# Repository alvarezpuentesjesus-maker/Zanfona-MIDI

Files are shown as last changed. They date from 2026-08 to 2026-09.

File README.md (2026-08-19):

# Zanfona-MIDI

En este repositorio se recogen tanto los archivos de fabricación mecánica como el software y los esquemas electrónicos para la fabricación de un prototipo funcional de una zanfona MIDI. Este proyecto ha sido desarrollado como TFG para el grado en Robótica en la Universidad de Santiago de Compostela.

<p align="center">
  <a href="#">
    Terminada_Trasera
  </a>
</p>

## [Archivos_MIDI](Archivos_MIDI)

Para que el instrumento produzca sonido, es necesario conectarlo a un software de producción musical. En este caso se ha escogido [LMMS Studio](https://lmms.io/). 

Se han preparado archivos diferentes en esta carpeta, para interpretar varios instrumentos, gracias a la web de [Musical Artifacts](https://musical-artifacts.com/), que proporciona samples gratuitos.

## [Electrónica](Electronica) 

En esta carpeta están contenidos los diferentes esquemáticos utilizados en este proyecto. Además, se ha añadido el archivo de simulación empleado para la placa Resitor_Ladder, llamdo Simulación_Resistor_Ladder.txt.
Para emplear este archivo correctamente es necesario cargarlo en el simulador de circuitos de [MasterPLC](https://masterplc.com/simulador/).

Se adjunta aquí mismo una tabla con las conexiones de la placa principal para mayor facilidad de lectura:

<div align="center">

| Pin | Nombre | Conexión |
| :---: | :---: | :---: |
| 1 | GP0 | Manivela SDA |
| 2 | GP1 | Manivela SCL |
| 3 | GND | |
| 4 | GP2 | Display cuerdas 1 |
| 5 | GP3 | Display cuerdas 2 |
| 6 | GP4 | Display cuerdas 3 |
| 7 | GP5 | Display cuerdas 4 |
| 8 | GND | |
| 9 | GP6 | Display cuerdas 5 |
| 10 | GP7 | Display cuerdas 6 |
| 11 | GP8 | Display cuerdas 7 |
| 12 | GP9 | Display cuerdas 8 |
| 13 | GND | |
| 14 | GP10 | Display cuerdas 9 |
| 15 | GP11 | Display cuerdas Estado |
| 16 | GP12 | CLK Encoder Cuerdas |
| 17 | GP13 | DT Encoder Cuerdas |
| 18 | GND | |
| 19 | GP14 | SW Encoder Cuerdas |
| 20 | GP15 | CLK Encoder Perro |
| 21 | GP16 | DT Encoder Perro |
| 22 | GP17 | SW Encoder Perro |
| 23 | GND | |
| 24 | GP18 | CLK Encoder Bending |
| 25 | GP19 | DT Encoder Bending |
| 26 | GP20 | SW Encoder Bending |
| 27 | GP21 | NC |
| 28 | GND | |
| 29 | GP22 | NC |
| 30 | RUN | NC |
| 31 | GP26 A0 | Teclado Resistencias |
| 32 | GP27 A1 | NC |
| 33 | ADC GND | |
| 34 | GP28 A2 | Bending |
| 35 | ADV Vref | NC |
| 36 | 3v3 Vout | |
| 37 | 3v3 En | NC |
| 38 | GND | |
| 39 | VSYS 5V* | NC |
| 40 | VBUS 5V | |

</div>

## [Hardware](Hardware)

Aquí se ven contenidos los archivos de fabricación mecánica. Como archivo principal Archivo_Corte.CDR, permite el uso de una cortadora láser para fabricar todas las piezas necesarias en MDF de 3mm. Se facilitan también los archivos individuales de cada pieza en formato DXF en la carpeta [Piezas_individuales](Hardware/Piezas_individuales).

## [Software](Software)

Este proyecto se ha desarrollado utilizando una Raspberry Pi Pico como microcontrolador principal. A su vez, se ha necesitado el firmware de [CircuitPython](https://circuitpython.org/board/raspberry_pi_pico/) para poder utilizarla como USB nativo, además de poder cargarle las librerías necesarias de [Adafruit_MIDI](https://github.com/adafruit/Adafruit_CircuitPython_MIDI). En este caso se deben tener incluidas las librerías: adafruit_bus_device, adafruit_midi y adafruit_register.

Una vez configurada la Raspberry, es necesario copiar en el interior de su carpeta el archivo [code.py](Software/code.py) y la carpeta [dependencias](Software/dependencias), para el correcto funcionamiento de la zanfona.

Por otra parte, se facilita un archivo llamado [MEDIAS.py](Software/MEDIAS.py), que se utiliza para medir el rango de tensión de cada tecla pulsada y completar la tabla contenida en el archivo [variables.py](Software/dependencias/variables.py).

## BOM

En la siguiente tabla se puede ver el BOM tanto de elementos de hardware como electrónica para todo lo necesario en este proyecto:

<div align="center">

| Categoría | Referencia | Descripción | Cantidad | Precio ud | Precio Total | Proveedor |
| :---: | :---: | :--- | :---: | :---: | :---: | :---: |
| Electrónica | SC0915 | Microcontrolador Raspberry Pi Pico | 1 | 3,51 € | 3,51 € | [TME](https://www.tme.eu/es/details/sc0915/raspberry-pi-sistemas-embebidos/raspberry-pi/raspberry-pi-pico/) |
| Electrónica | CF1/4W-10K | Resistencia 10K 100ud | 1 | 0,87 € | 0,87 € | [TME](https://www.tme.eu/es/details/cf1_4w-10k/resistencias-tht/sr-passives/) |
| Electrónica | CF1/4W-150R | Resistencias 150Ω 100ud | 1 | 0,90 € | 0,90 € | [TME](https://www.tme.eu/es/details/cf1_4w-150r/resistencias-tht/sr-passives/) |
| Electrónica | CF1/4W-2K | Resistencias teclado 2K 100ud | 1 | 0,74 € | 0,74 € | [TME](https://www.tme.eu/es/details/cf1_4w-2k/resistencias-tht/sr-passives/) |
| Electrónica | TAL220B | Galga extensiométrica 5Kg | 1 | 9,49 € | 9,49 € | [Amazon](https://www.amazon.es/QUARKZMAN-Digital-Precisi%C3%B3n-Electr%C3%B3nica-Port%C3%A1til/dp/B0G6Z576YL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) |
| Electrónica | AD620 | Amplificador Galga | 1 | 5,79 € | 5,79 € | [Funduino](https://funduinoshop.com/es/modulos-electronicos/otros/amplificador/amplificador-de-tension-milivoltios-ad620) |
| Electrónica | OSX10201-R | Barra Led 10 segmentos Roja | 1 | 0,82 € | 0,82 € | [TME](https://www.tme.eu/es/details/osx10201-r/pantallas-led-otros/optosupply/) |
| Electrónica | EC11E12-15P30C-SW | Encóders | 3 | 1,42 € | 4,26 € | [TME](https://www.tme.eu/es/details/ec11e12-15p30c-sw/codificadores-incrementales/sr-passives/) |
| Electrónica | AS5600 | Sensor Magneto resistivo | 1 | 0,99 € | 0,99 € | [Aliexpress](https://es.aliexpress.com/item/1005006349632569.html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) |
| Electrónica | XY308-2P 2.54MM GREEN | Conector Bloque Terminal 10ud | 1 | 2,29 € | 2,29 € | [TME](https://www.tme.eu/en/details/xy308-2p-2.54-gn/pcb-terminal-blocks/xinya/xy308-2p-2-54mm-green/) |
| Electrónica | XHP-3 | Conector JST 3 pines 2.5mm Hembra | 4 | 0,06 € | 0,24 € | [TME](https://www.tme.eu/es/details/xhp-3/conectores-de-senal-raster-2-50mm/jst/) |
| Electrónica | B3B-XH-A (LF)(SN) | Conector JST 3 pines 2.5mm Macho | 4 | 0,09 € | 0,36 € | [TME](https://www.tme.eu/es/details/b3b-xh-a/conectores-de-senal-raster-2-50mm/jst/b3b-xh-a-lf-sn/) |
| Electrónica | XHP-4 | Conector JST 4 pines 2.5mm Hembra | 2 | 0,07 € | 0,14 € | [TME](https://www.tme.eu/es/details/xhp-4/conectores-de-senal-raster-2-50mm/jst/) |
| Electrónica | B4B-XH-A (LF)(SN) | Conector JST 4 pines 2.5mm Macho | 2 | 0,11 € | 0,22 € | [TME](https://www.tme.eu/es/details/b4b-xh-a/conectores-de-senal-raster-2-50mm/jst/b4b-xh-a-lf-sn/) |
| Electrónica | XHP-5 | Conector JST 5 pines 2.5mm Hembra | 6 | 0,06 € | 0,36 € | [TME](https://www.tme.eu/es/details/xhp-5/conectores-de-senal-raster-2-50mm/jst/) |
| Electrónica | B5B-XH-A (LF)(SN) | Conector JST 5 pines 2.5mm Macho | 6 | 0,16 € | 0,96 € | [TME](https://www.tme.eu/es/details/b5b-xh-a/conectores-de-senal-raster-2-50mm/jst/b5b-xh-a-lf-sn/) |
| Electrónica | Cable AWG 26 | Bobina de cable para usos varios | 1 | 8,99 € | 8,99 € | [Amazon](https://www.amazon.es/HAAMNING7-conexi%C3%B3n-el%C3%A9ctrico-bricolaje-maquetas/dp/B0G6BPVY99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) |
| Electrónica | PCBs | Coste producción PCBs | 3 | 5,00 € | 15,00 € | [PCBWay](https://www.pcbway.es/) |
| **Subtotal Electrónica** | | | | | **55,93 €** | |
| Hardware | B5X10/BN3 | Tornillos M5 10mm 100ud | 1 | 3,18 € | 3,18 € | [TME](https://www.tme.eu/es/details/b5x10_bn3/tornillos/bossard/1004077/) |
| Hardware | M3X20/D912-A2 | Tornillos M3 20mm 100ud | 1 | 2,63 € | 2,63 € | [TME](https://www.tme.eu/es/details/m3x20_d912-a2/tornillos/kraftberg/) |
| Hardware | M3X30/D912-A2 | Tornillos M3 30mm 100ud | 1 | 3,10 € | 3,10 € | [TME](https://www.tme.eu/es/details/m3x30_4762_8bl/tornillos/reca/00823-30-000-1000/) |
| Hardware | B3/BN124 | Tuercas M3 5,5mm 100ud | 1 | 0,63 € | 0,63 € | [TME](https://www.tme.eu/es/details/b3_bn124/tuercas/bossard/1090615/) |
| Hardware | ST-093/1 | Punteras conexiones teclas M3 20ud | 2 | 1,09 € | 2,18 € | [TME](https://www.tme.eu/es/details/st-093_1/conectores-no-aislados/ninigi/) |
| Hardware | Eje de acero 8mm x 200mm | Eje de acero 8mm x 200mm | 1 | 3,71 € | 3,71 € | [Amazon](https://www.amazon.es/precisi%C3%B3n-inoxidable-ondulado-endurecido-adicional/dp/B07VMSMGLC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) |
| Hardware | Cable de acero 1mm | Cable de acero 1mm | 1 | 2,49 € | 2,49 € | [Leroy Merlin](https://www.leroymerlin.es/productos/cable-de-acero-galvanizado-de-1mm-de-y-10-m-de-longitud-89125664.html) |
| Hardware | Clavijas 3L3R | Clavijas Guitarra | 1 | 8,45 € | 8,45 € | [Amazon](https://www.amazon.es/QWORK-clavijero-Afinaci%C3%B3n-el%C3%A9ctricas-galvanizada/dp/B0B2JW5N1K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) |
| Hardware | TABLERO MDF 120X60X0,3CM | Madera en plancha 120x60x0,3cm | 1 | 6,30 € | 6,30 € | [Obramat](https://www.obramat.es/productos/tablero-mdf-120x60x0-3cm-10114503.html) |
| Hardware | Hilo elástico 0,5mm | Hilo elástico 0,5mm | 1 | 0,94 € | 0,94 € | [Amazon](https://www.amazon.es/Hilo-Nailon-el%C3%A1stico-Transparente-50mm/dp/B09ZHVVFNJ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) |
| **Subtotal Hardware** | | | | | **33,61 €** | |
| **Coste Total de fabricación** | | | | | **89,54 €** | |

</div>

Los precios pueden variar con el tiempo o incluso no tener existencias, se recomienda utilizar la referencia y buscar enlaces de compra adaptados a la disponibilidad del momento.

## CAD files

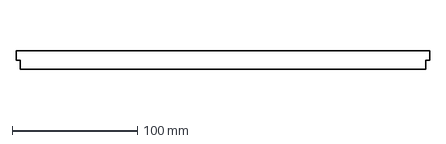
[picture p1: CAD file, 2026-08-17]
Hardware/Piezas_Individuales/Caja_Teclas/Caja_Tope_Teclas.dxf
330.0 x 15.0 mm

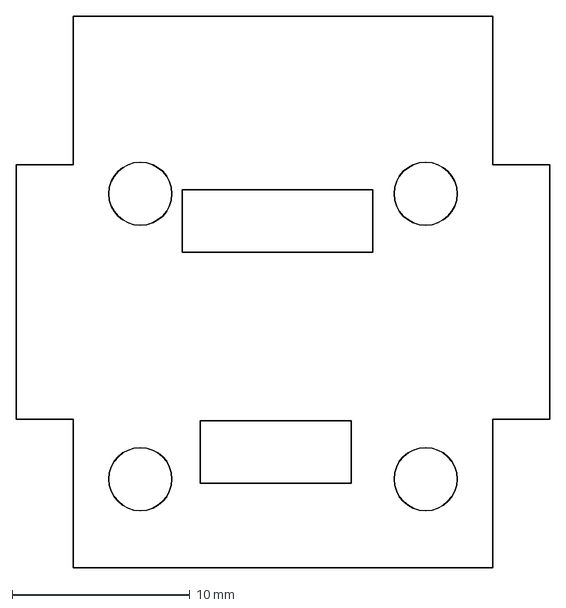
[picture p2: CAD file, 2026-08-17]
Hardware/Piezas_Individuales/Cuerpo/Encoder_Frente.dxf
30.0 x 31.0 mm

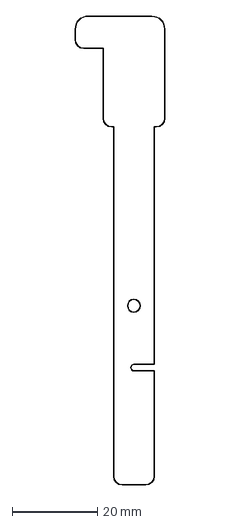
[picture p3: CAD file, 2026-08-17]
Hardware/Piezas_Individuales/Teclas/Inferior_6_Superior.dxf
21.0 x 110.0 mm

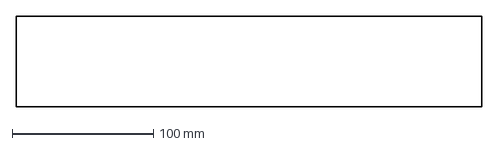
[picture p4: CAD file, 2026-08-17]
Hardware/Piezas_Individuales/Caja_Teclas/Caja_Tapa.dxf
330.0 x 64.0 mm

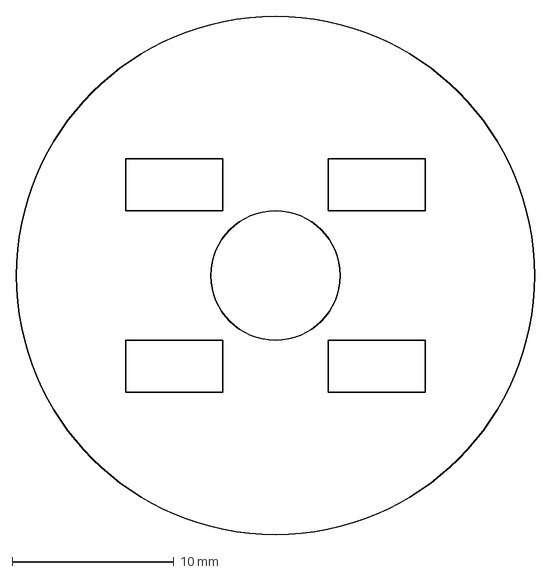
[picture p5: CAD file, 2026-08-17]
Hardware/Piezas_Individuales/Cuerpo/Tope_Eje.dxf
32.0 x 32.0 mm

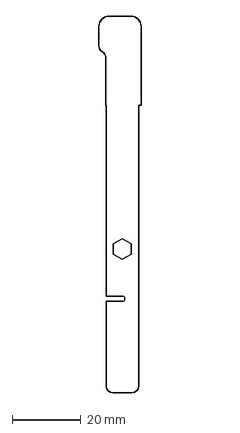
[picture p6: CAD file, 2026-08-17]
Hardware/Piezas_Individuales/Teclas/Inferior_11_Inferior.dxf
12.3 x 110.0 mm

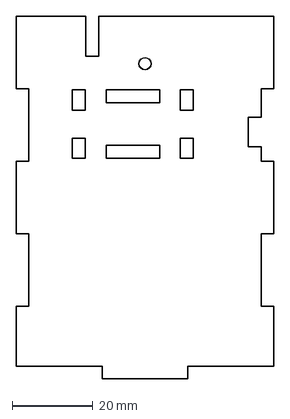
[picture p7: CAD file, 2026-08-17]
Hardware/Piezas_Individuales/Caja_Teclas/Caja_Lateral_Clavija.dxf
64.0 x 90.0 mm

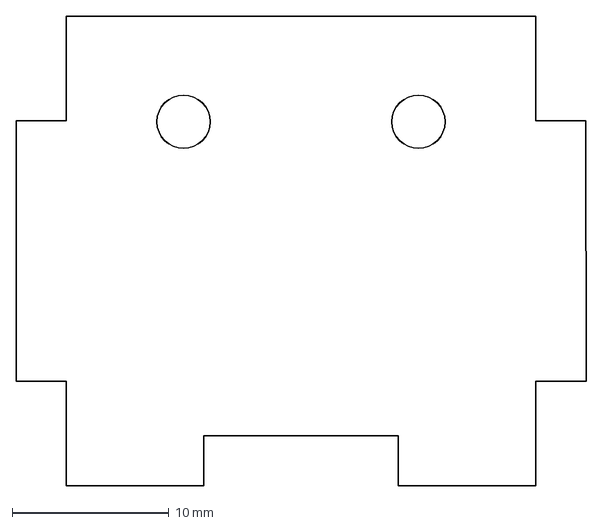
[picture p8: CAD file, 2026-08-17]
Hardware/Piezas_Individuales/Cuerpo/SopoerteRueda_Superior_Lateral.dxf
36.4 x 30.0 mm

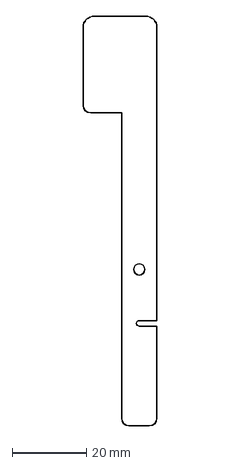
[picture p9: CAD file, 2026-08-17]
Hardware/Piezas_Individuales/Teclas/Inferior_8_Superior.dxf
19.8 x 110.0 mm

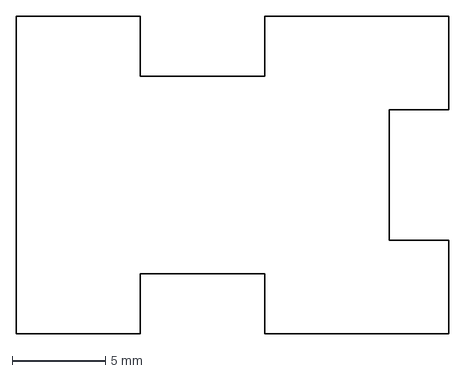
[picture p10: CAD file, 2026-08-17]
Hardware/Piezas_Individuales/Caja_Teclas/Clavija_Lateral.dxf
23.2 x 17.0 mm

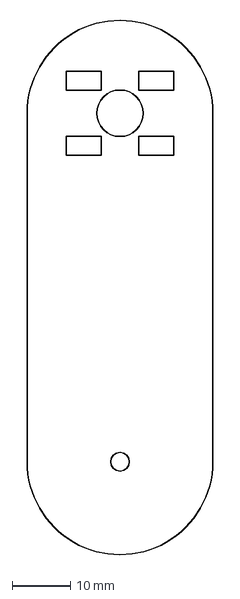
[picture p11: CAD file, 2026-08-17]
Hardware/Piezas_Individuales/Cuerpo/Manivela.dxf
32.0 x 93.4 mm

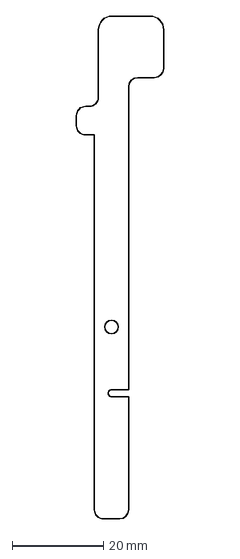
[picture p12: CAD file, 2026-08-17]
Hardware/Piezas_Individuales/Teclas/Inferior_14_Superior.dxf
19.1 x 110.0 mm

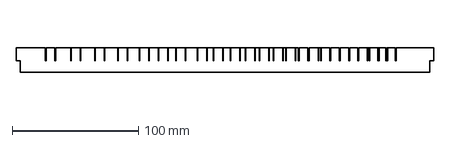
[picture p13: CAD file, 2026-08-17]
Hardware/Piezas_Individuales/Caja_Teclas/Caja_Tope_Teclas_Gomas.dxf
330.0 x 19.0 mm

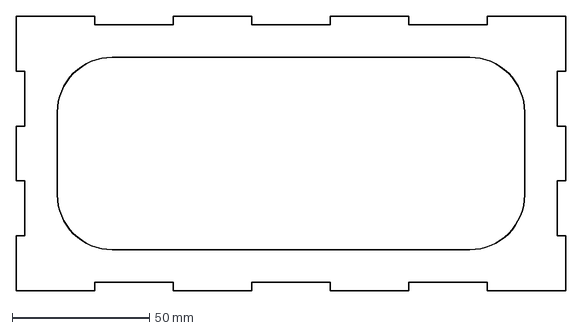
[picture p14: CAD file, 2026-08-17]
Hardware/Piezas_Individuales/Cuerpo/Cuerpo_Refuerzo1.dxf
200.0 x 100.0 mm

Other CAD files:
Hardware/Piezas_Individuales/Teclas/Inferior_10_Inferior.dxf
Hardware/Piezas_Individuales/Caja_Teclas/Caja_Tapa_Enganches.dxf
Hardware/Piezas_Individuales/Cuerpo/Cuerpo_Refuerzo2.dxf
Hardware/Piezas_Individuales/Teclas/Inferior_9_Inferior.dxf
Hardware/Piezas_Individuales/Caja_Teclas/Caja_Base.dxf
Hardware/Piezas_Individuales/Caja_Teclas/Caja_Lateral_Galga.dxf
Hardware/Piezas_Individuales/Caja_Teclas/Caja_Lateral_Largo1.dxf
Hardware/Piezas_Individuales/Caja_Teclas/Caja_Lateral_Largo2.dxf
Hardware/Piezas_Individuales/Caja_Teclas/Caja_Soporte_Teclas.dxf
Hardware/Piezas_Individuales/Caja_Teclas/Clavija_Arriba.dxf
Hardware/Piezas_Individuales/Caja_Teclas/Clavija_Perno.dxf
Hardware/Piezas_Individuales/Cuerpo/Cuerpo_Base.dxf
Hardware/Piezas_Individuales/Cuerpo/Cuerpo_Lateral_Corto.dxf
Hardware/Piezas_Individuales/Cuerpo/Cuerpo_Lateral_Largo1.dxf
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

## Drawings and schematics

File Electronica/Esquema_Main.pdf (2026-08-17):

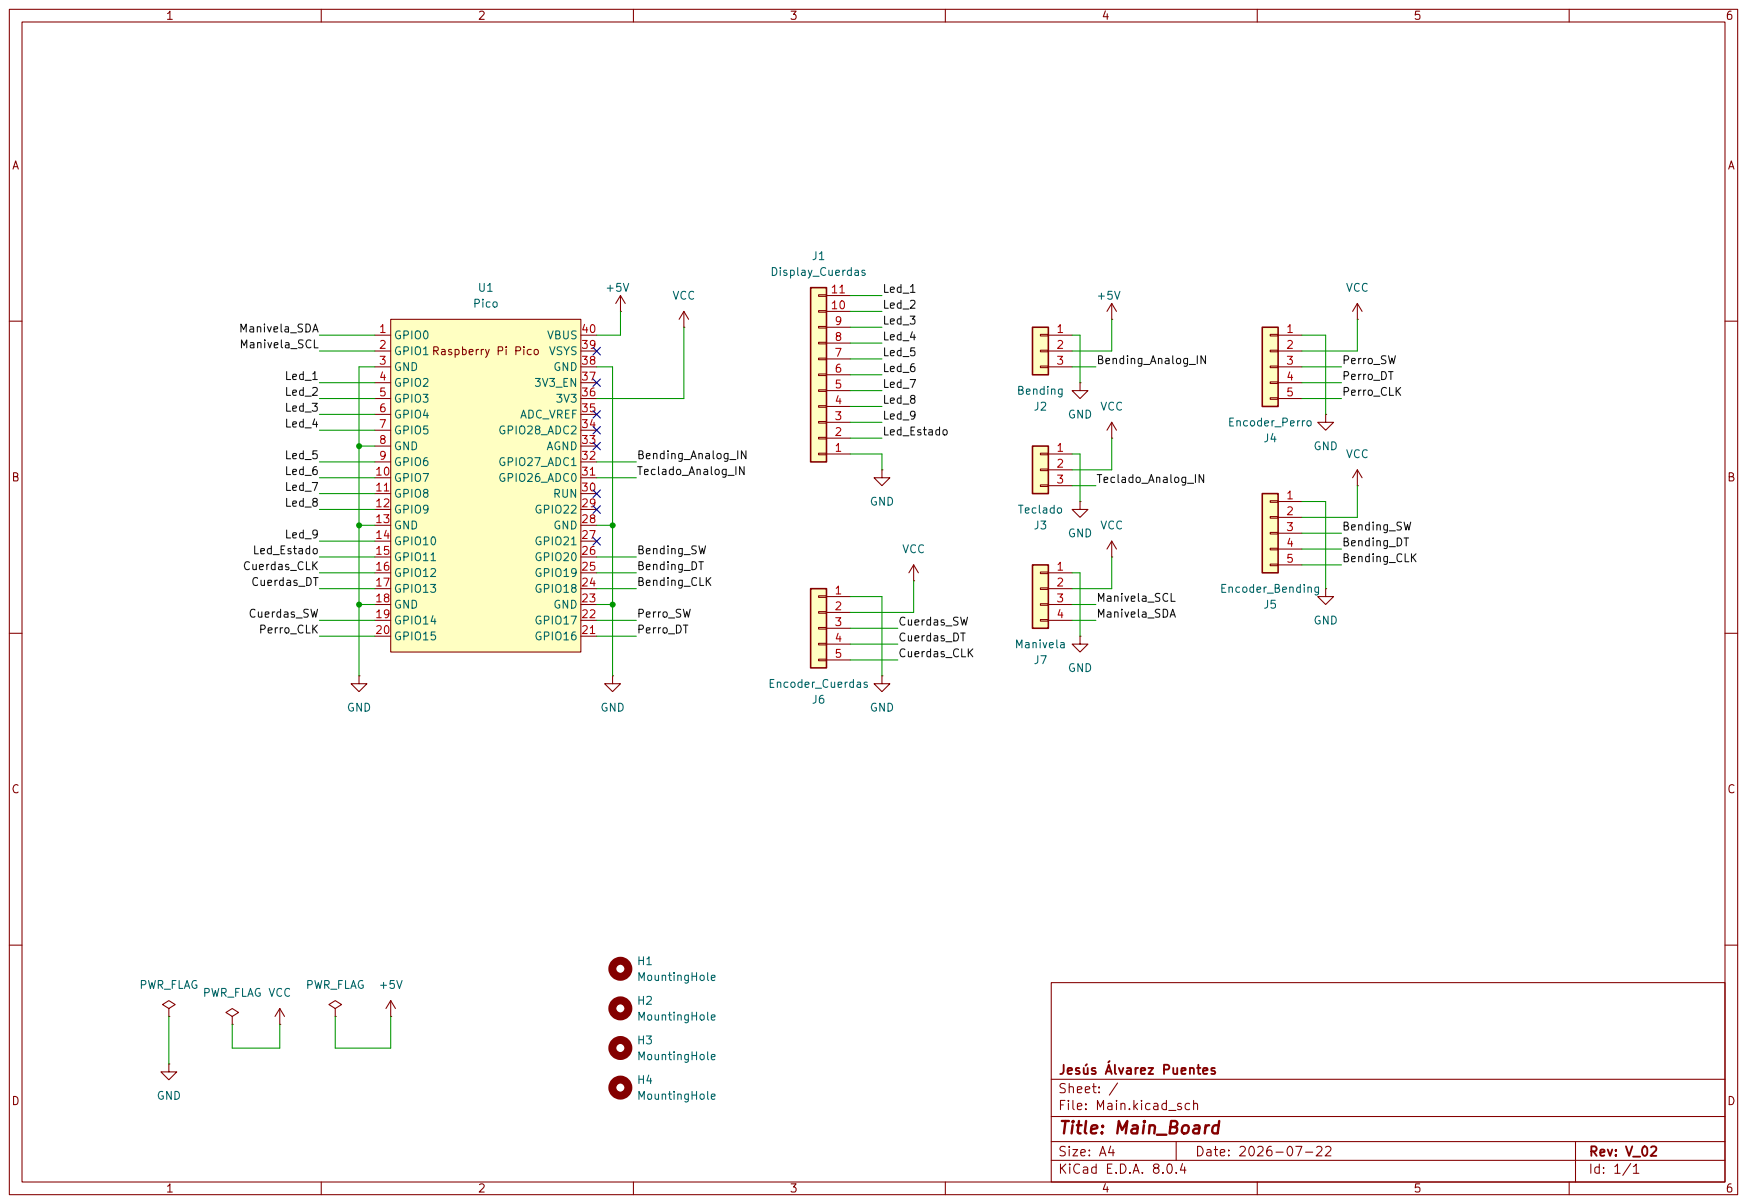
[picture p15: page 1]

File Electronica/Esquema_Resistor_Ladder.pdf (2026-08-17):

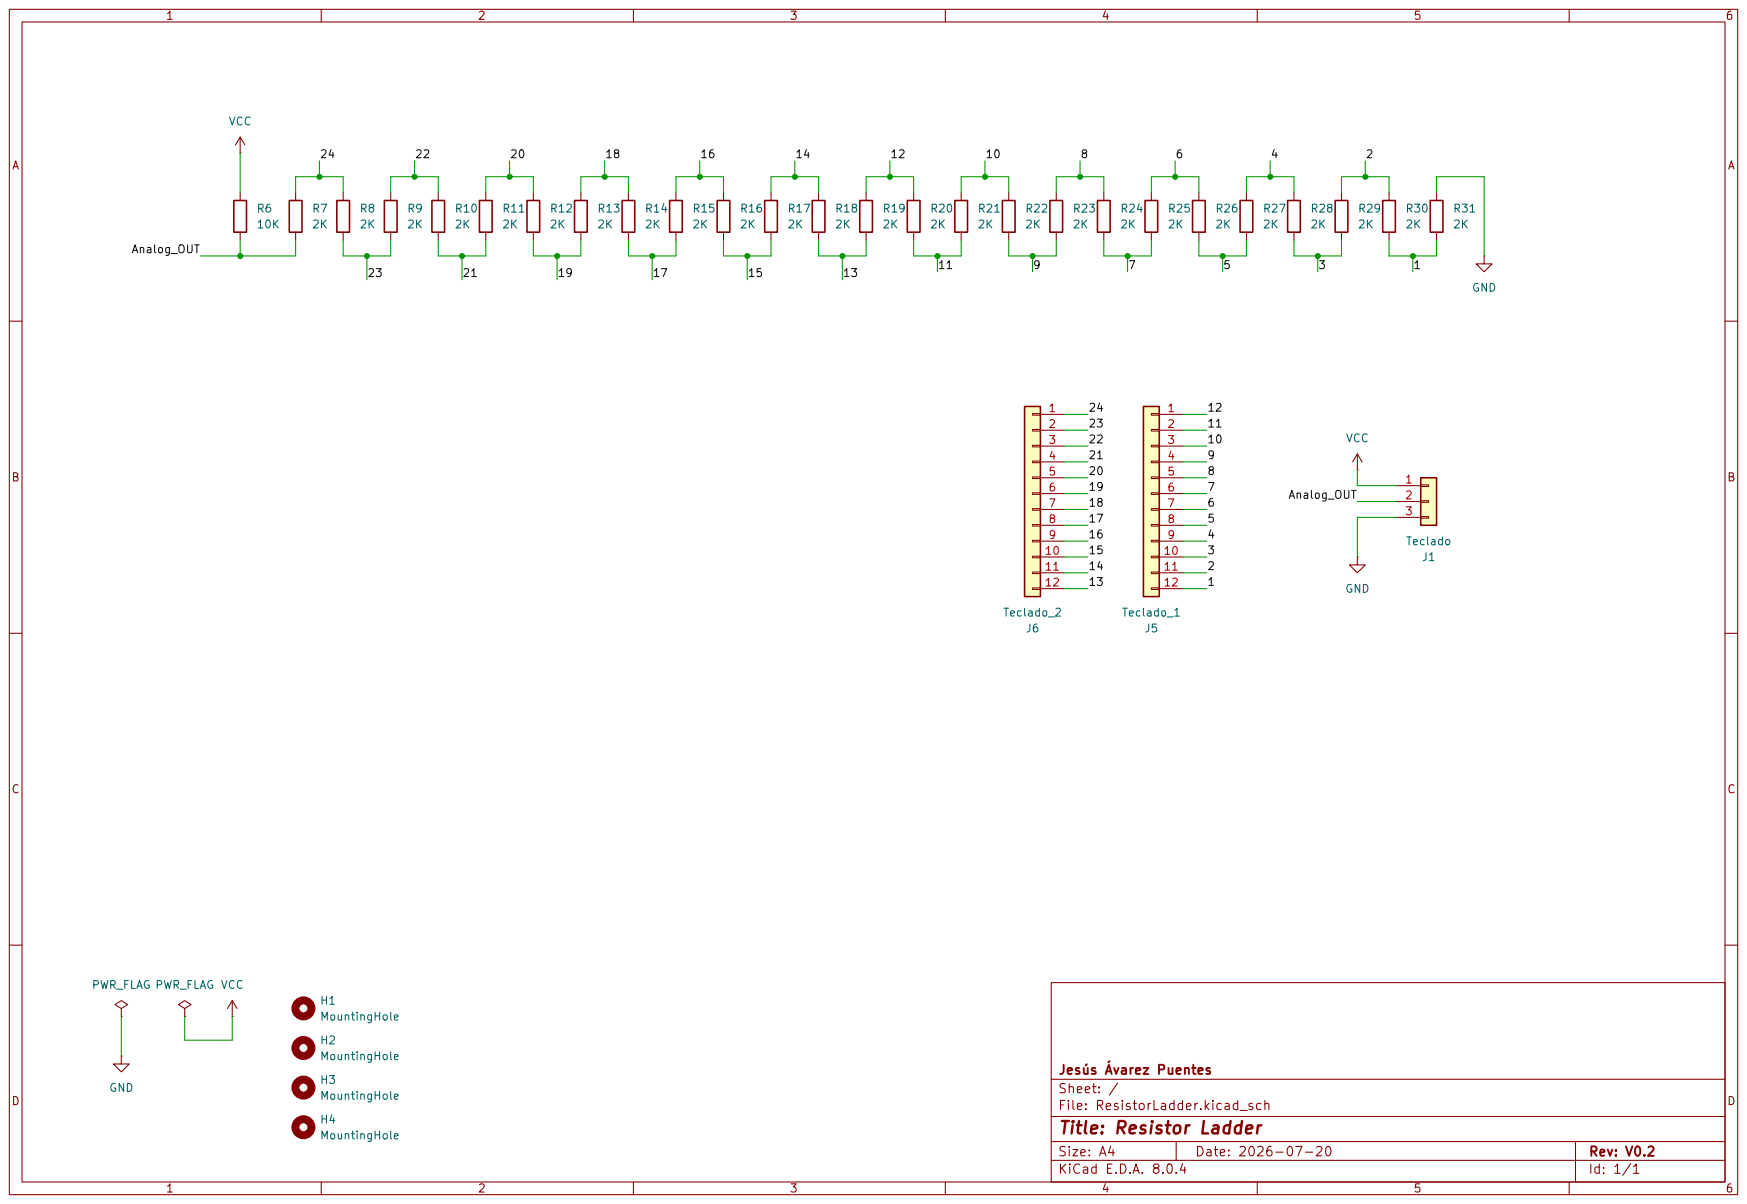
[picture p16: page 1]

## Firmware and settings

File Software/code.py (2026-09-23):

"""
Módulo Principal: Zanfona MIDI
==============================

Bucle principal de ejecución para el control de la Zanfona MIDI.
Gestiona el bucle  en tiempo real: lectura de la manivela (encoder), 
teclado analógico, galga extensiométrica (bending), ejecución del perro, 
y selector de cuerdas.

Información del archivo:
- Archivo: code.py
- Autor: Jesús Álvarez Puentes
- Fecha: 2026-07-28
- Versión: 0.1
- Licencia: CC BY-NC-SA 4.0
- Dependencias: 
    * CircuitPython (time)
    * dependencias.zanfona
"""

from dependencias.zanfona import *


# Hacer una media con los valores del bending para ver de qué partimos y usar eso para definir el "0"
sumatorio_bending = 0

for i in range (1000):
    valor_bending = bending_in.value
    sumatorio_bending += valor_bending
    time.sleep(0.001)

media_bending = sumatorio_bending/1000

print(f"Media bending: {media_bending}")



# --------- TEMA CUERDAS ----------

# FALTA LA GESTIÓN DE LAS CUERDAS SIMPÁTICAS !!!!!!!!

zanfona = Zanfona()

zanfona.agregar_cuerda(("cantora", "G4", 0))
zanfona.agregar_cuerda(("cantora", "G3", 1))
zanfona.agregar_cuerda(("cantora", "G3", 2)) # OJO, se ve que no le gusta esa parte a la zonafona que hay

zanfona.agregar_cuerda(("bordon", "C3", 3))
zanfona.agregar_cuerda(("bordon", "G2", 4))
zanfona.agregar_cuerda(("bordon", "G2", 5))

zanfona.agregar_cuerda(("trompeta", "C4", 6))
zanfona.agregar_cuerda(("trompeta", "C4", 7))
zanfona.agregar_cuerda(("trompeta", "C4", 8))

# zanfona.agregar_cuerda(("perro", "D4", 9)) # LMMS Studio Perro.WAW
zanfona.agregar_cuerda(("perro", "C4", 10)) # Fluidsynth o LMMS Studio Perro.sf2



print("Estado cuerdas:")
print(zanfona.estado_selector_cuerdas())


while True:
    # ----- Lectura de manivela -----
    lectura_encoder = lectura_angulo()
    angulo = (lectura_encoder * 360.0) / 4096.0
    t_angulo = time.monotonic()

    # Gestión de la manivela
    if angulo_ant is not None:
        dt_angulo = t_angulo - t_angulo_ant

        if dt_angulo > 0:

            # Corrección salto 360°
            delta = correcion_angulo(angulo, angulo_ant)

            # -------- VELOCIDAD --------
            vel = delta / dt_angulo  # velocidad en º/s
            vel_f = media_movil_velocidad(vel)

            t_vel = t_angulo

        # De esta forma se pueden ignorar valores bajos de velocidad derivados de ruido
        if vel_f is not None and vel_f > velocidad_base_manivela:

            # -----  Actualización de las teclas -------
            lectura_teclas = teclado_in.value
            tension = (lectura_teclas/65535)*3.3
            tecla_pulsada = rango2Teclas(tension)
            # print(f"Tension: {tension} || Tecla: {tecla_pulsada}")


                     
            # De esta forma no la actualiza si no es necesario
            # Un pequeño antibounce suprimientdo cambios de menos de un tiempo pertinente
            if tecla_pulsada != None and tecla_pulsada != tecla_ant and (time.monotonic() - tiempo_ultima_tecla) > anti_bounce:
                print(f"Tension: {tension} || Tecla: {tecla_pulsada}")
                zanfona.teclado.cambiaTono(tecla_pulsada)
                # Se debe activar girar, para actualizar los valores de las teclas pulsadas
                tecla_ant = tecla_pulsada
                ACTUALIZADO = False # De esta forma actualiza los valores
                tiempo_ultima_tecla = time.monotonic()

            
            # Se mide la entrada analógica de la galga con el amplificador
            valor_bending = bending_in.value
            #print(f"Valor bending: {valor_bending}")

            # Por simplificación inicial, se define un umbral que superar habiendo hecho la meida previamente
            # Esto se hace porque la galga va a estar en tensión inicialmente y no tendrá un vlaor de 0
            if valor_bending > media_bending + zanfona.umbral_bending and BENDING_ACTIVO == True:
                # Esta variable simplemente se usa para que se mande el mensaje una única vez
                if BENDING == False:  
                    # Si se supera este humbral se pone el valor de pitch bend hacia arriba   
                    bend_val = 12000       
                    print("BENDEADNDO")  
                    zanfona.rueda.bending(bend_val)
                    BENDING = True  

            # Si tiene
            elif (BENDING == True):
                zanfona.rueda.bending()
                BENDING = False



            # Al marcar el giro, actualiza todo lo que se haya modificado antes   
            # Se valorará el uso de la velocidad para el volumen, pero de esta forma no se reenvían notas innecesariamente
            if ACTUALIZADO == False: 
                zanfona.rueda.girar()
                ACTUALIZADO = True
                # print("Sonando")


            # Simplemente si se supera una velocidad hace sonar el perro, si no lo para
            if vel_f > zanfona.umbral_perro and zanfona.perro.activa and PERREANDO == False:
                zanfona.rueda.perreando()
                PERREANDO = True
                # print("Perreando")
               

            elif vel_f < zanfona.umbral_perro and  zanfona.perro.activa and PERREANDO == True:
                zanfona.rueda.perreando(False)
                PERREANDO = False

        else:
            zanfona.rueda.parar()
            zanfona.rueda.perreando(False)
            ACTUALIZADO = False
            PERREANDO = False


    # ------------ PERRO ------------
    perro_lectura_clk = perro_clk.value 

    if perro_clk_ant and not perro_lectura_clk:
        zanfona.modificar_umbral_perro(perro_dt.value)

        # --- Botón ---
    perro_lectura_boton = perro_sw.value  
    # Detectar pulsación con debounce y activas o desactivar el perro
    if not perro_lectura_boton and perro_boton_ant and (time.monotonic() - perro_tiempo_boton_ant) > anti_bounce:
        if zanfona.perro.activa == True:
            zanfona.perro.des_activar()
            print("Desactivando perro")
            
        else:
            zanfona.perro.activar()
            print("Activando perro")
        perro_tiempo_boton_ant = time.monotonic()
    # ------------------------------------

    # ------------ BENDING ------------
    bending_lectura_clk = bending_clk.value 

    if bending_clk_ant and not bending_lectura_clk:
        zanfona.modificar_umbral_bending(bending_dt.value)

        # --- Botón ---
    bending_lectura_boton = bending_sw.value  
    # Detectar pulsación con debounce y activas o desactivar el perro
    if not bending_lectura_boton and bending_boton_ant and (time.monotonic() - bending_tiempo_boton_ant) > anti_bounce:
        if BENDING_ACTIVO == True:
            BENDING_ACTIVO = False
            zanfona.rueda.bending()
            print("Desactivando bending")
            
        else:
            BENDING_ACTIVO = True
            print("Activando bending")
        bending_tiempo_boton_ant = time.monotonic()
    # ------------------------------------

    # ------------ SELECTOR CUERDAS ------------
    cuerdas_lectura_clk = cuerdas_clk.value

    if cuerdas_clk_ant and not cuerdas_lectura_clk:
        zanfona.indice_selector_cuerdas(cuerdas_dt.value)

        # --- Botón ---
    cuerdas_lectura_boton = cuerdas_sw.value  
    # Detectar pulsación con debounce para activar o desactivar la cuerda 
    if not cuerdas_lectura_boton and cuerdas_boton_ant and (time.monotonic() - cuerdas_tiempo_boton_ant) > anti_bounce:
        zanfona.actualiza_estado_cuerdas()
        cuerdas_tiempo_boton_ant = time.monotonic()

    zanfona.actualiza_selector_cuerdas()
    # ------------------------------------

    angulo_ant = angulo # Tema manivela                
    t_angulo_ant = t_angulo 

    perro_clk_ant = perro_lectura_clk # Tema perro
    perro_boton_ant = perro_lectura_boton

    bending_clk_ant = bending_lectura_clk # Tema bending
    bending_boton_ant = bending_lectura_boton

    cuerdas_clk_ant = cuerdas_lectura_clk # Tema selector cuerdas
    cuerdas_boton_ant = cuerdas_lectura_boton

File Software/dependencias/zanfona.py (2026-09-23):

"""
Módulo de Clases: Zanfona MIDI
==============================

Contiene la definición del modelo de objetos del instrumento:
- Cuerda: Representación de cuerdas (cantora, bordón, trompeta, perro) y envío MIDI.
- Rueda: Gestión del estado de reproducción según el giro de la manivela.
- Teclado: Mapeo y cambio de tono sobre las cuerdas cantoras.
- Zanfona: Clase contenedora y gestora de la interfaz con los selectores y umbrales.

Información del archivo:
- Archivo: dependencias/zanfona.py
- Autor: Jesús Álvarez Puentes
- Fecha: 2026-07-28
- Versión: 0.1
- Licencia: CC BY-NC-SA 4.0
- Dependencias:
    * adafruit_midi (MIDI, NoteOn, NoteOff, PitchBend)
    * usb_midi
    * dependencias.fenciones
"""


from dependencias.fenciones import *



class Cuerda:

    def __init__(self, tipo, tono_base, canal):
        """
        tipo: Tipo de cuerda "cantora", "bordon", "trompeta", "perro", "simpatica"
        tono_base: Nota MIDI base número entero o notación inglesa
        canal: Canal de comunicación del 0 al 15
        """
        
        self.tipo = tipo.lower()
        self.canal = canal

        # Básicamente el estado de la cuerda
        self.activa = True

        self.midi = MIDI(midi_out=usb_midi.ports[1], out_channel= self.canal)


        # Puesto que se puede definir el tono base con un entero o con la nota
        # Se comprueba en qué caso se encuentra
        if isinstance(tono_base, int):
            self.tono_base = tono_base
        elif isinstance(tono_base, str):
            self.tono_base = nota2MIDI(tono_base)

        # En el caso de las cantoras se podrá modificar su tono a lo largo de la ejecución,
        # con lo que se definirá el tono actual y el tono anterior para esa gestión
        if self.tipo == "cantora":
            self.tono_actual = self.tono_base
            self.tono_anterior = self.tono_base

    def des_activar(self):
        self.suena(False)   # Primero deja de sonar por si las moscas
        self.activa = False # Luego se desactiva

    def activar(self):
        self.activa = True

    def suena(self, onOff = True,  volumen = 100):
        """
        onOff: False desactiva el tono, True activa
        volumen: se define con la velocidad de la rueda y modifica el volumen 

        Por defecto activa el tono

        El tono que suene en cada cuerda se define por variables internas de cada objeto
        """

        # Primero asegura que esta cuerda esté activa
        # Si lo que se quiere es que deje de sonar, se compreba que sea cantora o no si se "apaga" el tono
        # Si quiere que suene se comprueba también, se apagará el tono anterior en caso de ser cantora y se activará el nuevo
        if self.activa == True:

            if onOff == False:
                if self.tipo == "cantora":
                    self.midi.send(NoteOff(self.tono_anterior, 0))
                else:
                    self.midi.send(NoteOff(self.tono_base, 0))

            if onOff == True:
                if self.tipo == "cantora":
                    self.midi.send(NoteOn(self.tono_actual, volumen))
                    # Si cambió el tono se apaga el anterior y se actualiza, si no no
                    if self.tono_actual != self.tono_anterior:
                        self.suena(False)
                        self.tono_anterior = self.tono_actual
                else:
                    self.midi.send(NoteOn(self.tono_base, volumen))

class Rueda:
    def __init__(self):
        """
        Esta clase gesiona el sonido de las cuerdas.
        Si la cuerda está en modo activo la hace sonar y si está en modo "perreando" hace sonar el perro
        """
        self.cuerdas = []
        self.perro = None

    def agregar_cuerda(self,cuerda):
        """
        En un principio se esperaba que agregases un objeto cuerda desde la variable cuerda
        """
        self.cuerdas.append(cuerda)

    def girar(self, velocidad = 100):
        """
        Se reocrrerán las cuerdas asegurando que estén activas y se harán sonar a la velocidad indicada
        """

        for cuerda in self.cuerdas:
            # El perro solo "perreando"
            if cuerda.activa == True and cuerda.tipo is not "perro":
                cuerda.suena(volumen = velocidad)

            

    def parar(self):
        """
        Simplemente hace que todas las cuerdas dejen de sonar
        """
        for cuerda in self.cuerdas:
            if cuerda.activa == True:
                cuerda.suena(False)

    def perreando(self, onOff = True):
        """
        Si la velocidad supera un margen establecido, se activará el perro
        """
        if onOff == True and self.perro.activa == True:
            self.perro.suena()
        else:
            self.perro.suena(False)

    # Estemétodo aplica bending a las cuerdas cnatoras correspondiendo con el valor de entrada
    # analógica medida en la galga. POr defecto el valor central de 8192 para el tono base
    def bending(self, bend_val = 8192):
        for cuerda in self.cuerdas:
            if cuerda.activa == True and cuerda.tipo == "cantora":
                    cuerda.midi.send(PitchBend(bend_val))

class Teclado:
    def __init__(self):
        """
        Esta clase se encarga del tono de las cuerdas cantoras según la tecla pulsada
        """
        self.cuerdas = []

    def agregar_cuerda(self,cuerda):
        """
        En principio solo debería admitir cantoras o como mucho simpáticas
        """
        self.cuerdas.append(cuerda)

    def cambiaTono(self, tecla = None):
        """
        Este método se encarga de cambiar el tono actual de las cuerdas según la tecla pulsada
        cogerá la tecla y sumará un offset a las cuerdas proporcional a la tecla
        """

        # Esto se hace cogiendo el tono base y sumando la relación establecida con la tecla.
        # teniendo en cuenta que las notas MIDI son números enteros simplemente se suma
        # Valorará si hay una tecla pulsada y asignará el nuevo tono para que suene, si no hay nada
        # se quedará con el tono base (cuerda al aire)
        
        if tecla is not None:
            for cuerda in self.cuerdas:
                if cuerda.activa == True:
                    cuerda.tono_actual = cuerda.tono_base + tecla
        else:
            for cuerda in self.cuerdas:
                if cuerda.activa == True:
                    cuerda.tono_actual = cuerda.tono_base
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

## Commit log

2026-08-17 Subiendo todos los archivos
    [Cabeza_1.dxf, Cabeza_10.dxf, Cabeza_2.dxf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]
2026-08-17 Update README.md
    BOM
2026-08-18 Añadido de comentario inical en los códigos
